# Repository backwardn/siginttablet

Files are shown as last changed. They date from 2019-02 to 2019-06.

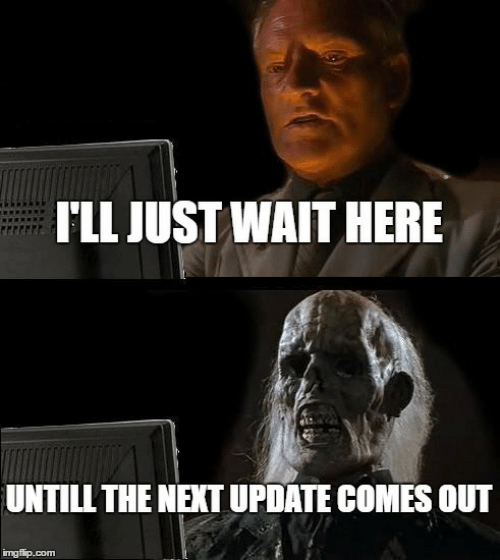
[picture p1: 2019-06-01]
CircleCityCon 2019/assets/ill-just-wait-here-untill-the-next-update-comes-out-26150274.png

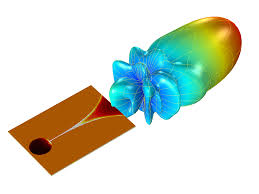
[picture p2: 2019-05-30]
CircleCityCon 2019/assets/vivaldi smith.jpeg

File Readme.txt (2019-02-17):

This is the repository for a Signals Intelligence Tablet, as I will be discussing at the 2019 CircleCityCon

--------------------------------------------
“Who said something? What did they say? Where did they say it? What can I do with it?” These are the questions people have when working with unknown radio systems. This is the art and science of Signals Intelligence (SigInt).

We discuss the basic requirements for working with SigInt, along with a sample platform using a Raspberry Pi and a RTLSDR radio receiver. The discussion will then briefly touch on other hardware that can enable SigInt work, that are not incorporated in the demo platform. We then dive into the software stack that makes SigInt work.

The following software will be used: Linux (Raspbian), RPITX, RTLSDR libraries, GnuRadio (gr-inspector), GQRX, and other accompanying tools. We will use FCC ID’s, manual scanning of spectrum, and gr-inspector to find and target potentially vulnerable frequencies and protocols as well as show how exploits could commence. We will attempt a live demo of such an attack using a system the presenter brings in.
--------------------------------------------

This document will be populated appropriately showing an assembly, recommended 3d printing settings, electrical routing, and configurations for the Raspbian and accompanying software.

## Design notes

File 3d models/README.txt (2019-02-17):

You will need a set of programs to work with these files.

The .fcstd is FreeCAD's data format. This software is Free Software and available for Windows/Mac/Linux. https://www.freecadweb.org/

The .stl's are provided for convenience and are a quick way to print the model. You should never edit STLs. Crappy triangles are crappy. I suggest using MeshLab for visual verification of a model. http://www.meshlab.net/

You will need a slicer to slice the STL to the appropriate gcode for your printer. I will not provide GCode files, since they will *not* work on your printer, unless you built the exact model. 

I would suggest for models 1-4, to print with 100% infill. For #5 (the lid), I have made specific instruction recomenndations for that in the directory.

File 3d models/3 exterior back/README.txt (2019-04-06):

If you have printed the "exterior back.stl" model, and you wish to incorporate a CrazyRadio without another 16h print, do the following:

1. Get a drill with a multitude of bits. 
2. Determine where you want the antenna.
3. Use the smallest bit to start the hole.
4. Work your way up slowly until you get between 6-7mm dia (or whatever that is in imperial)
5. Then work your SMA into the hole, and then tighten the nut. You might have to go back to step 4 if its too small. 
6. Done!

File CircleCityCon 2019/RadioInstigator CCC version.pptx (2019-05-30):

## RadioInstigator

Signals Intelligence Platform

## Who am I?

Josh Conway (CrankyLinuxUser)
FCC Amateur radio: KC9JEF

Facial Recog for your ‘Con (CPU bound, no gpu, no internet)
https://hackaday.com/2015/03/04/face-recognition-for-your-next-con/

Multisite Home/Office/Hackerspace Automation
https://hackaday.io/project/12985-multisite-homeofficehackerspace-automation
Thalmic Labs(North) Shuts Down Free Developer Access Update: It’s Back Again
https://hackaday.com/2014/11/18/thalmic-labs-shuts-down-free-developer-access/

## What is this “Radio” thing, anyways?

## Is this a radio? Is that a radio???

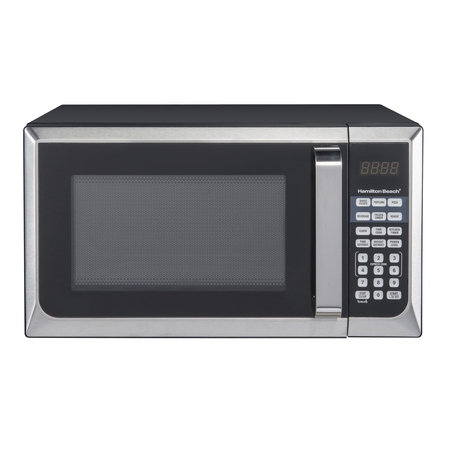
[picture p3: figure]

## They all are!

Definition (noun): The transmission and reception of electromagnetic waves of radio frequency, especially those carrying sound messages.
Definition (verb): communicate or send a message by radio.

## Signals Intelligence

Signals intelligence (SIGINT) is intelligence-gathering by interception of signals, whether communications between people (communications intelligence—abbreviated to COMINT) or from electronic signals not directly used in communication (electronic intelligence—abbreviated to ELINT).
-- Wikipedia

BUT WHY DO WE CARE???

## Common household things… Right?

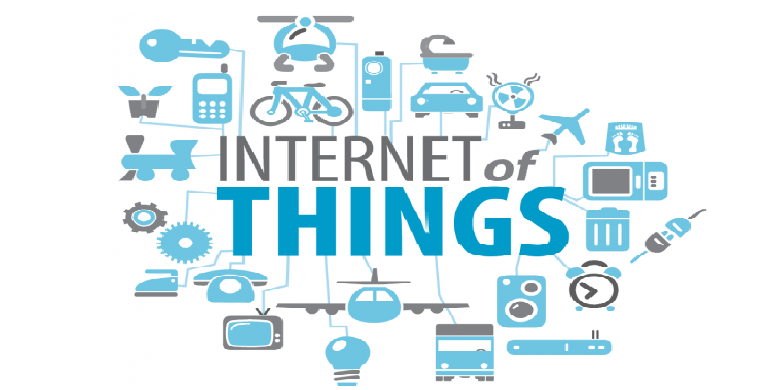
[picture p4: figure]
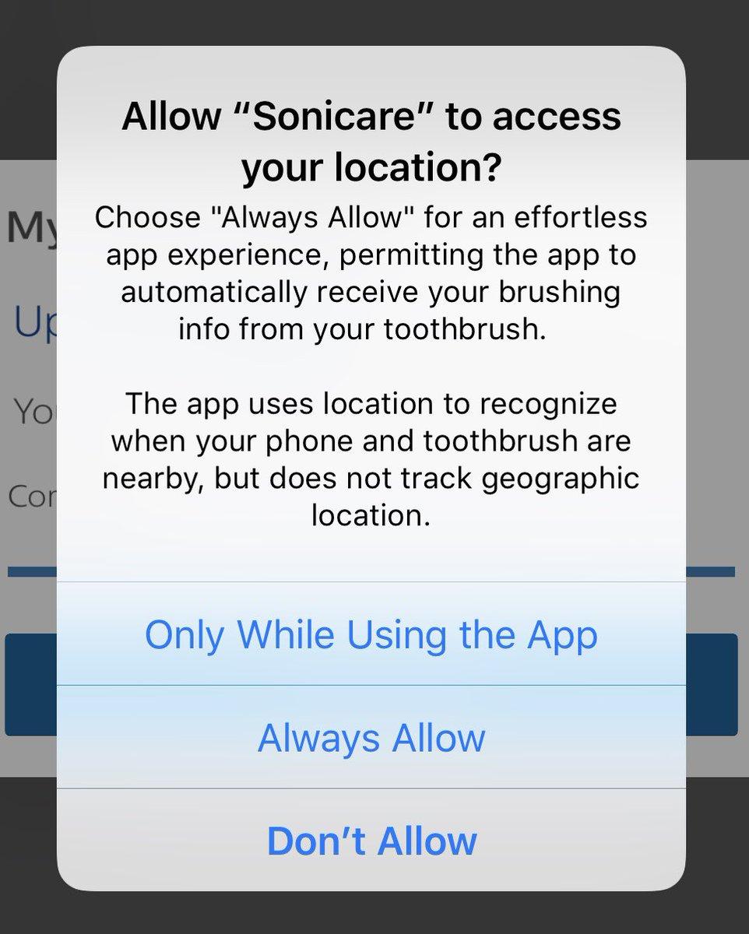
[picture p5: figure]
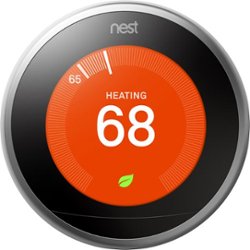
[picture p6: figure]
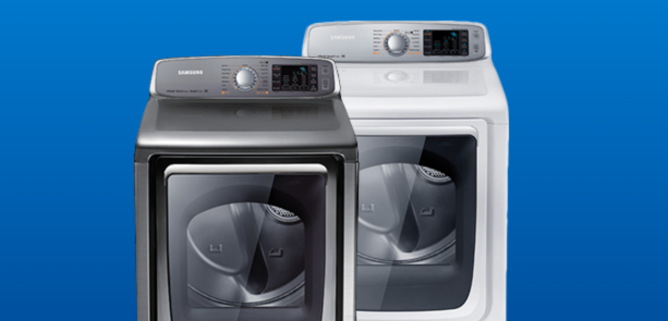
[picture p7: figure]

## Security? Not if we can get away without it!

How many of these are implemented on radios you own?
Are they secure?
Are you sure???

## …. Don’t mind if I do!

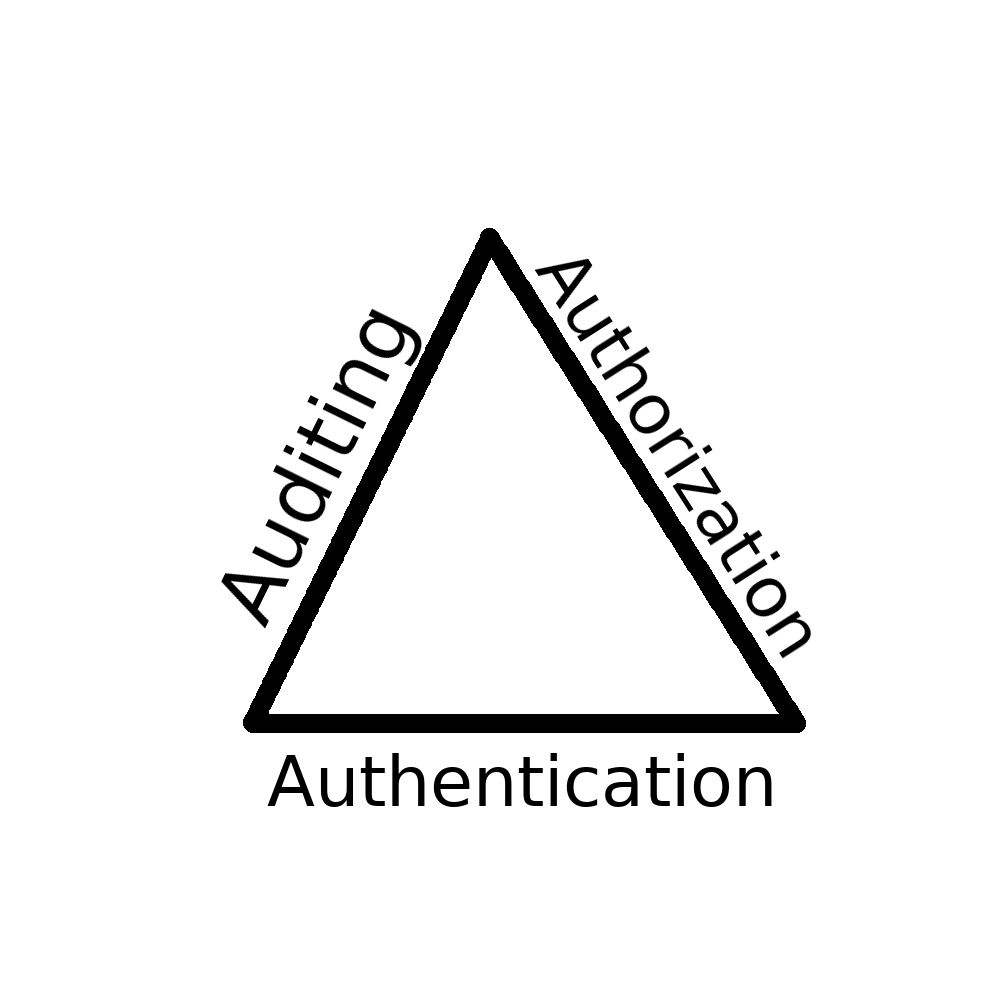
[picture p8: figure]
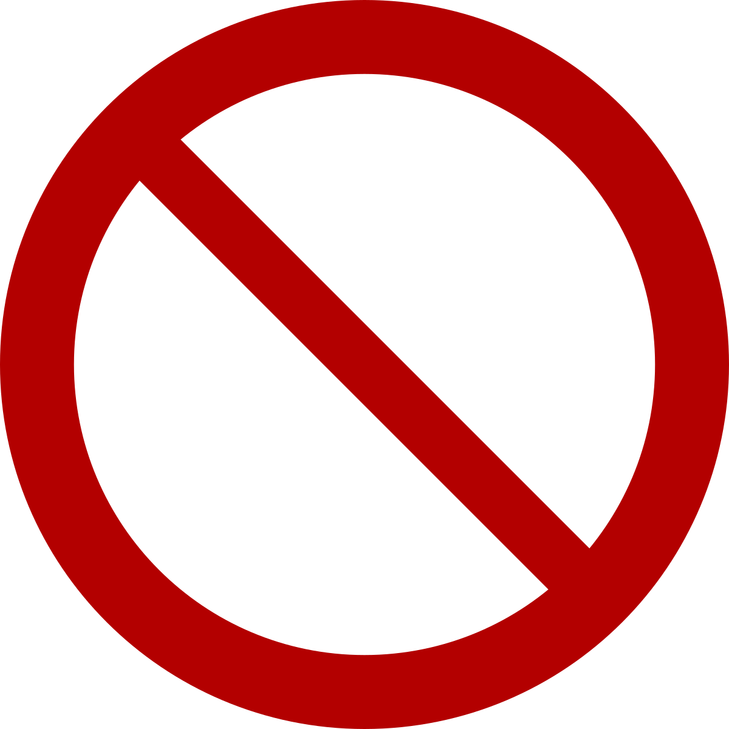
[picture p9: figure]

Unknown
hardware

Unencrypted

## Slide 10

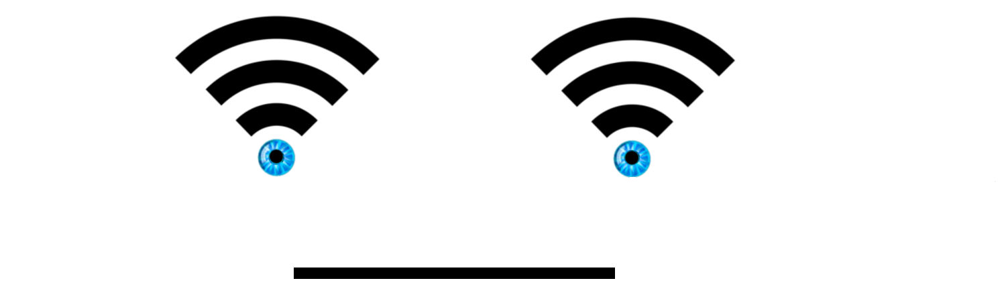
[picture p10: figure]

We are watching you

## My Platform - A $150 Signals Intelligence Tablet

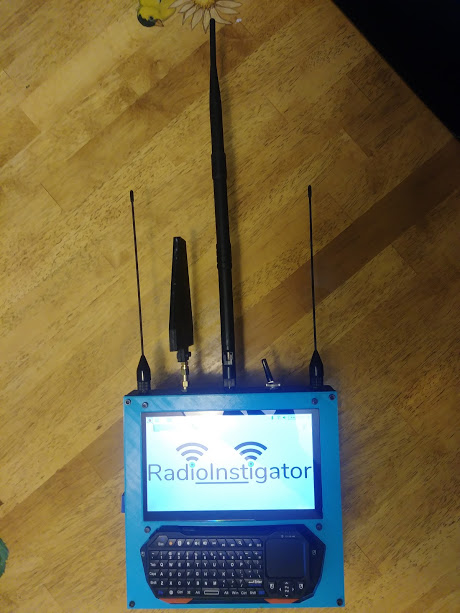
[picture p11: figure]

Raspberry Pi 3 B+
HDMI Touchscreen
RTL-SDR
Keyboard
Cool prints!

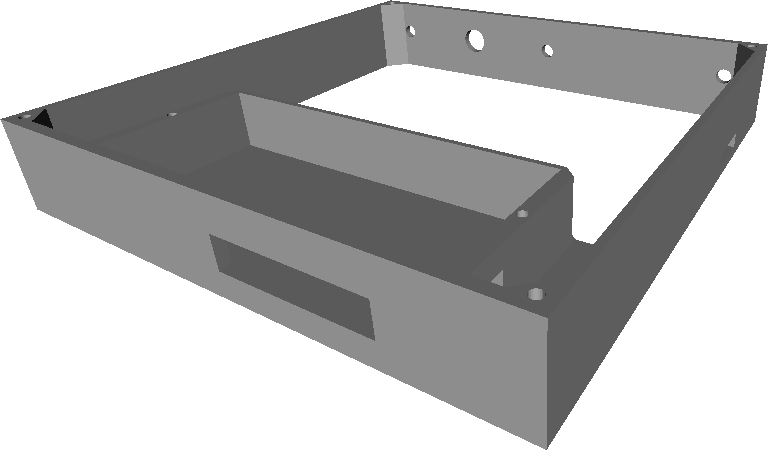
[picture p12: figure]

## You want to build one?

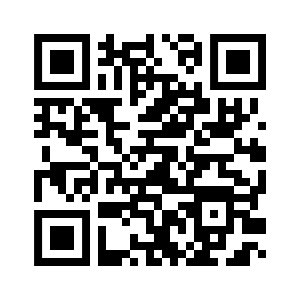
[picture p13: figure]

## SigInt on a shoestring or Dirty SigInt Deeds Done Dirt Cheap

## The Notorious RTL-SDR

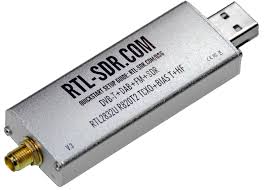
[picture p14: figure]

GOOD | BAD
Cheap Easy to obtain 24MHz-1766MHz 2.4MHz Bandwidth (window) | Cheap Sometimes dubious build quality Janky included antennas

## ADALM-PLUTO

GOOD | BAD
$100-$150 Uber-hackable (dual core Arm with Linux) 70MHz-6GHz (?!) 20MHz Bandwidth (window) Can run programs on device! | Can be hard to obtain 5mW Tx Janky included antennas USB2 limits overall bandwidth

## HackRF

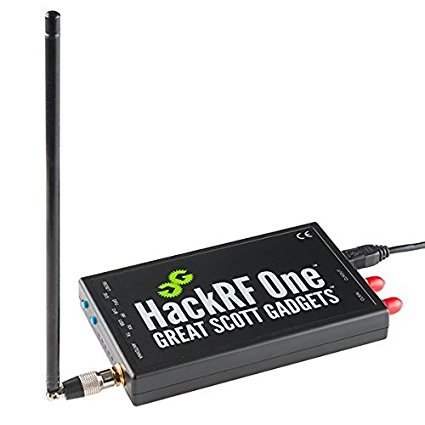
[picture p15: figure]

GOOD | BAD
~$300 Very well supported 1MHz-6GHz (?!?!) Sweep Mode – 8GHz/second | Simplex (Can Tx or Rx, not at the same time) 8 bit IQ

## KerberosSDR

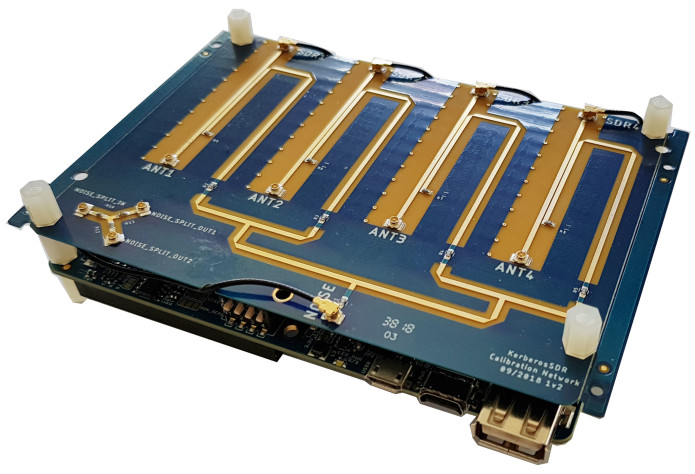
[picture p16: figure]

GOOD | BAD
~$125 Coherent Quad RTL-SDR 24MHz-1.7GHz | Toolchain very ‘raw’ because new 8 bit IQ

## Antennas … Because the ones with the SDR suck

## Omnidirectional Antennas

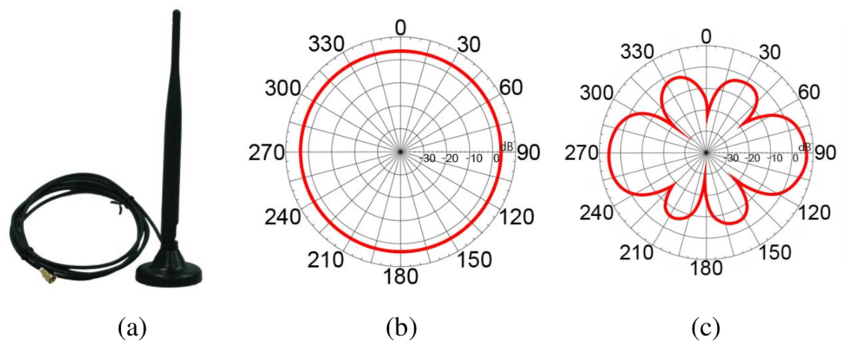
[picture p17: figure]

Horizontal
Polarization

Vertical
Polarization

## Yagi Antennas

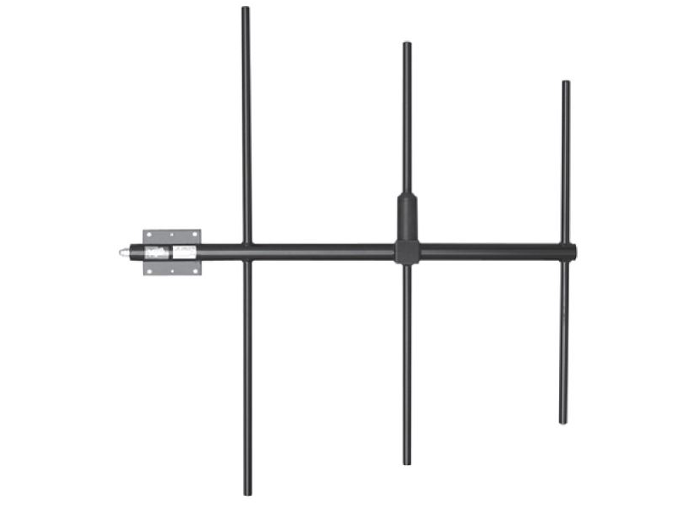
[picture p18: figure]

## Yagi Antennas cont’d

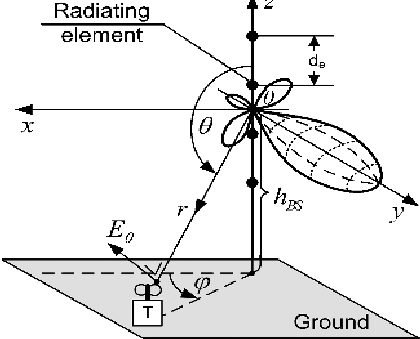
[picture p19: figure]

## Log Parabolic Antennas

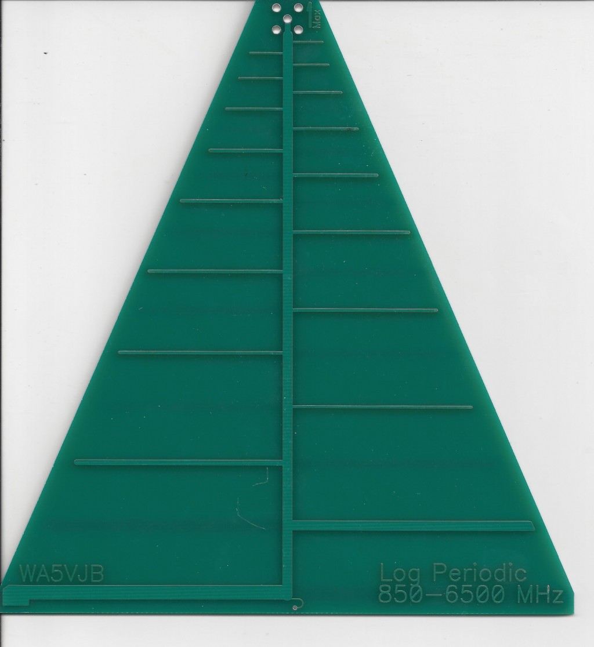
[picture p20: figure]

## Log Parabolic Antennas

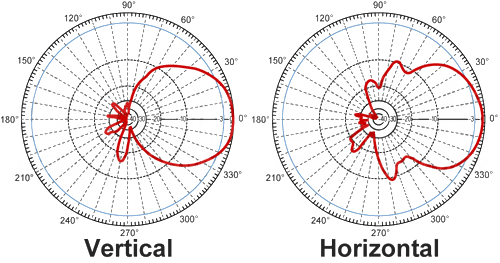
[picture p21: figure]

## Vivaldi Antennas

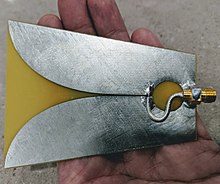
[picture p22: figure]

## Software Whisperer (OS, Libraries)

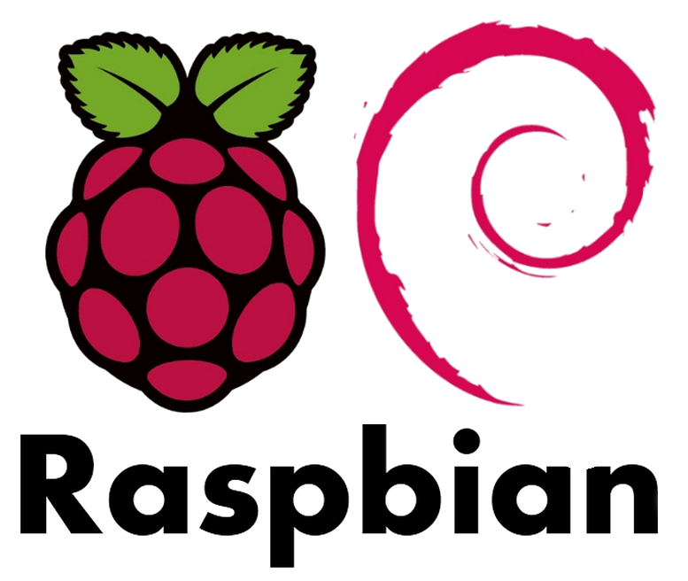
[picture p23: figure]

RPITX Library RTL_SDR Libraries

## Software / GQRX

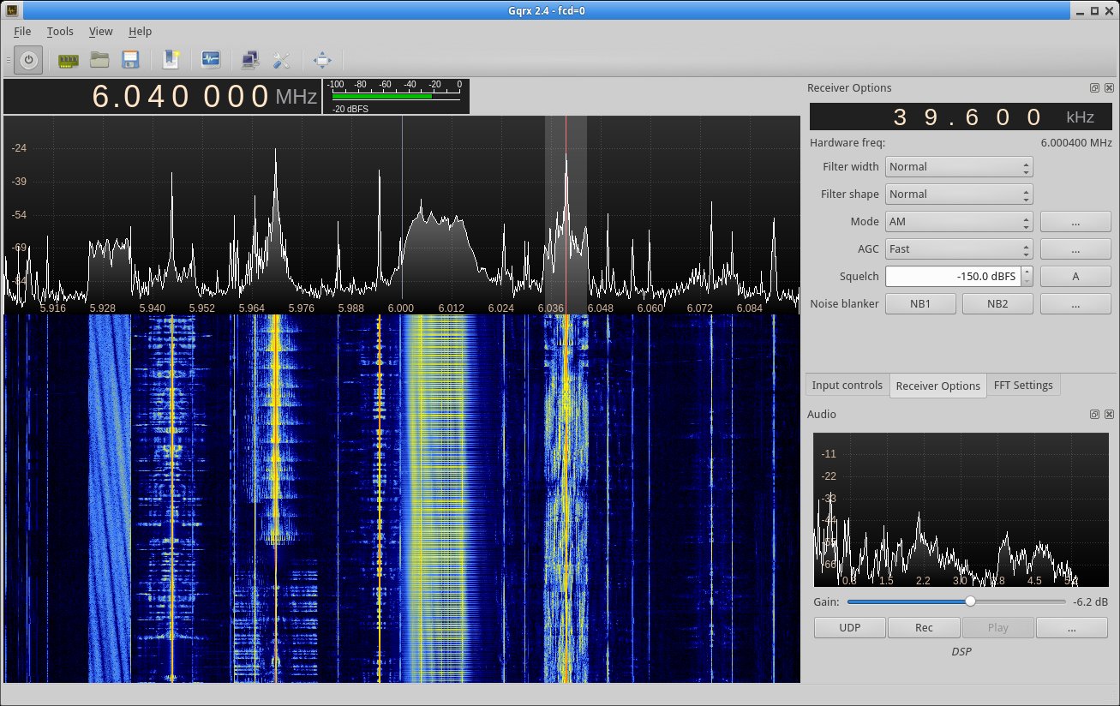
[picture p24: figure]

## Salamandra - Spy Microphone Detector

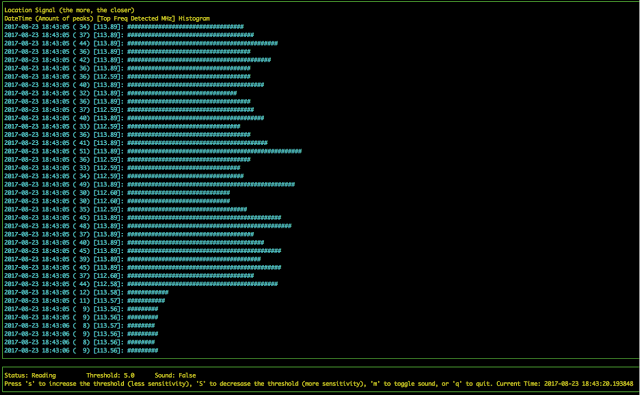
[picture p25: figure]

## TempestSDR - Every Monitor is Wireless

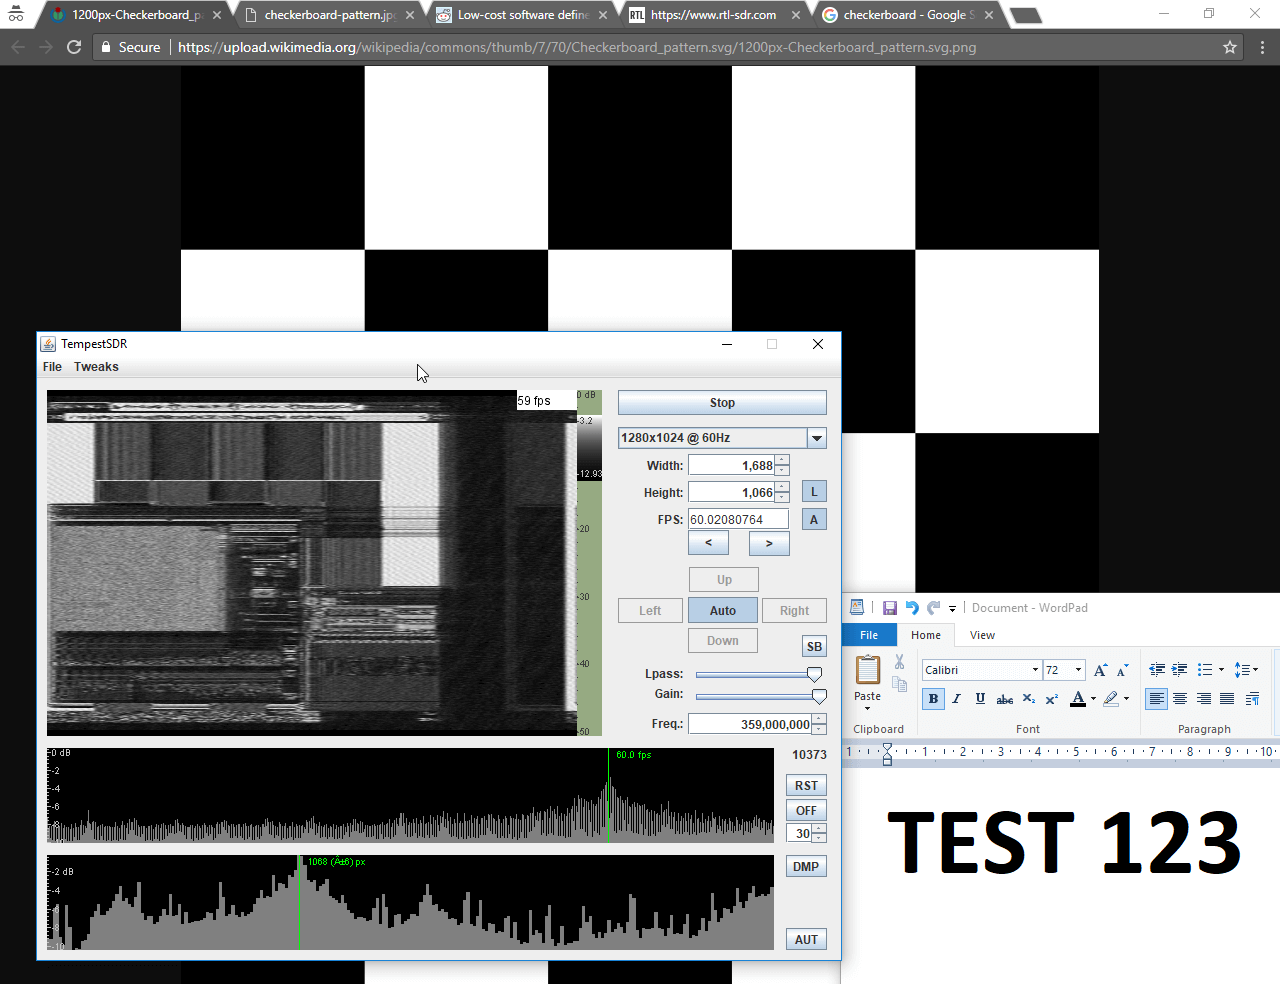
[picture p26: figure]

## Demotime….

## You want to build one?

## RadioInstigator

Signals Intelligence Platform

Josh Conway

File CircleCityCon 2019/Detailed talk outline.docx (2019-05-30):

Introduction (Section:2m, Total:2m)

A. (Myself, nickname, call sign)

B. (Anecdote how presenter forcefully open sourced closed hardware)

C. (Some renowned software presenter made for conventions)

D. Amateur radio operator and 'stuff hacker'

Basics of SigInt (Section:8m, Total:10m)

A. What is it?

1. Signals intelligence (SIGINT) is intelligence-gathering by interception of signals, whether communications between people (communications intelligence—abbreviated to COMINT) or from electronic signals not directly used in communication (electronic intelligence—abbreviated to ELINT). -- Wikipedia

B. Why do we care?

1. Unknown - Lots of things use radio. Equipment to read used to be $$$$ and relied on obscurity. Not now.

2. Unencrypted - Just like IoT, the E stands for Encryption. Most encryption is "we use diff. frequencies"

3. Unauthenticated \

4. Unauthorized |-- AAA Stack. Authentication, Authorization, Auditing. We'll have none of that.

5. Unauditable /

6. HACKED - Various holes enable taking control of endpoints, or listening in on sensitive data

SigInt Platforms (Section:16m , Total:26m)

A. Demo Platform

1. Raspberry Pi 3(All but PiB works)

a. I used RasPi 3 B+

2. Touchscreen that uses DSI or HDMI. Absolutely cannot use GPIO4

a. I used 7 in HDMI with usb power/touchscreen interface

3. RTLSDR dongle

a. I bought the el cheapo $8 Ali express special. Many will work. Make sure to get a TXCO (temp controlled oscillator) enabled

4. Good battery that outputs 2.5A or better USB

5. Antennas

a. omni

b. yagi

c. "weird" antennas

d. freq restrictions of hardware

i. RPi is 10KHz-1.5GHz TX

ii. RTLSDR is 24MHz-1.7GHz RX

iii. Ideal to find 2 antennas good from 24MHz-1.5GHz for symmetric bidirectional comms

6. Odds and ends

a. SMA and RP SMA connectors

b. Kapton tape for insulation

c. Lots and lots of time!

B. Other hardware you can use

1. Transmit & Receive

a. ADALM-PLUTO - 70MHz-6GHz full duplex. 5mw (DINKY) but is only $100 !

b. HackRF One - 1 MHz to 6 GHz single duplex. Tx OR Rx at any given time. ~$300

c. USRP SDRs - set top boxes, USB3 and/or ethernet. $$$$$$$$$

2. Receive only

a. Lots of RTLSDR usb devices. Prices range from $6 to $50. Many form factors. All use the Realtek R820T2 chip

a. KerberosSDR - Coherent "Quad Damage RTLSDR". Shipping Mid-late Jan 2019. Can do triangulation and signal tracking realtime.

b. NooElec NESDR SMArTee XTR - $40 for 65MHz-2300MHz

Software Stacks and Tools (Section:20m, Total:46m)

A. Review of the Fun Tools

1. Linux (Raspbian)

2. RPITX - Library that turns a dumb RPi into a full transmitter from 10KHz-1.5GHz . Also allows TX using raw IQ!

3. rtl_* commands - RTLSDR libraries and commands to natively interact with the RTLSDR. Other programs also rely on them incl RPITX

4. GnuRadio - Best way to build a targeted attack platform for a specific encoding and interaction. Steep curve to learn. Lots of modules.

a. gr-inspector is a ML module to find "Yummies" in signals. Think of this as a radio anomaly detector, so we don't have to look ourselves.

5. GQRX - Really QT frontend for Gnuradio to 'surf the waves' and see what's going on through a swath of spectrum

6. Salamandra - a tool to dynamically find spy microphones. Uses SDR closed loop to catch red handed. Detects AND locates.

7. TempestSDR - SDR tool that receives and decodes RF interference from monitors and shows what they display

(Note to reviewers: SigInt is 'The Next Big Thing', and has a great deal of focus on it right now. This section may expand as new tools are made by myself or the community in the coming months up to the talk. Other sections that will be reduced in time will be 'Other hardware you can use', followed by 'Demo Platform', as the knowledge to DIY it will be more widespread.)

Demonstration (Section:6m, Total:52m)

A. Record/Playback of audio over amateur radio frequency using Demo Platform and Baofeng

B. Replay attack demonstrated of a common 433MHz "arduino" module for IoT setups

Q&A (Section:8m, Total:60m)

Citations (shown on screen, not spoken):

A. RPi

B. RPITX

C. Gnu/Linux

D. Raspbian

E. GnuRadio

F. GQRX

G. Salamandra

H. TempestSDR

Acknowledgements (shown on screen, not spoken):

A. WarCollar industries, for getting me to think in this direction (and awesome story)

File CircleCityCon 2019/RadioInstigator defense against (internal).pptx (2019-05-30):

## RadioInstigator

Signals Intelligence Platform

## What is this “Radio” thing, anyways?


## They all are!

Definition (noun): The transmission and reception of electromagnetic waves of radio frequency, especially those carrying sound messages.
Definition (verb): communicate or send a message by radio.

## Signals Intelligence

Signals intelligence (SIGINT) is intelligence-gathering by interception of signals, whether communications between people (communications intelligence—abbreviated to COMINT) or from electronic signals not directly used in communication (electronic intelligence—abbreviated to ELINT).
-- Wikipedia

BUT WHY DO WE CARE???

## Common household things… Right?


## Security? Not if we can get away without it!


How many of these are implemented on radios you own?
Are they secure?
Are you sure???

## Awareness is Key … At work


## Awareness is Key … At home


## Awareness is Key … On Vacation


Spycam $37 , Amazon


USB cell spy *cable* $12


## Review of Platforms


RTL-SDR - $20 (avg)
Originally a TV tuner card for Asian TV
Can Receive only 20 MHz-1.7GHz

## Review of Platforms

ADALM-PLUTO - $100
Dedicated Transmit/Receive Software Radio
Transmit/Receive 70MHz-6GHz


## My Platform - A $150 Signals Intelligence Tablet


Raspberry Pi 3 B+
HDMI Touchscreen
RTL-SDR
Keyboard
Cool prints!


## Software Whisperer (OS, Libraries)


RPITX Library RTL_SDR Libraries

## Software / GQRX


## Salamandra - Spy Microphone Detector


## TempestSDR - Every Monitor is Wireless


## Demotime….

## You want to build one?


## RadioInstigator

Signals Intelligence Platform

Josh Conway

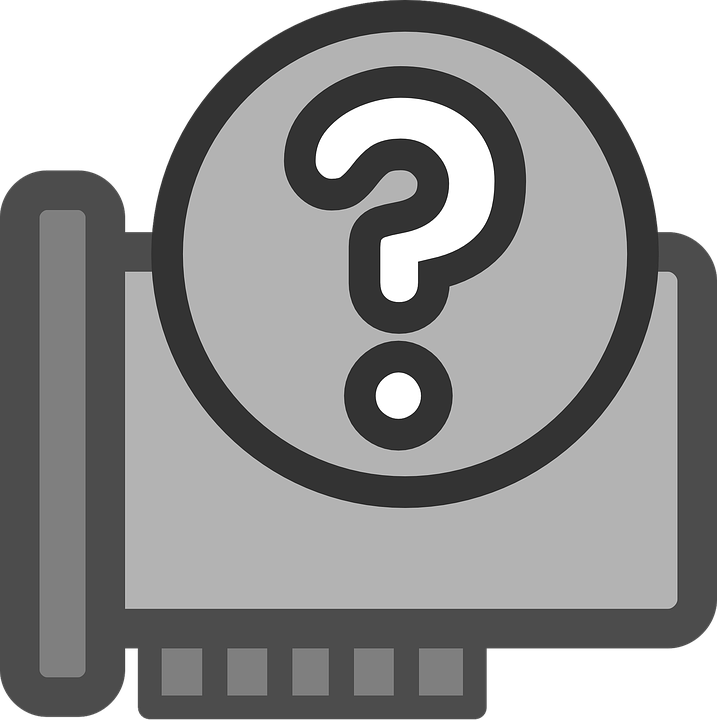
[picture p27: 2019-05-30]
CircleCityCon 2019/assets/unknown hardware.png

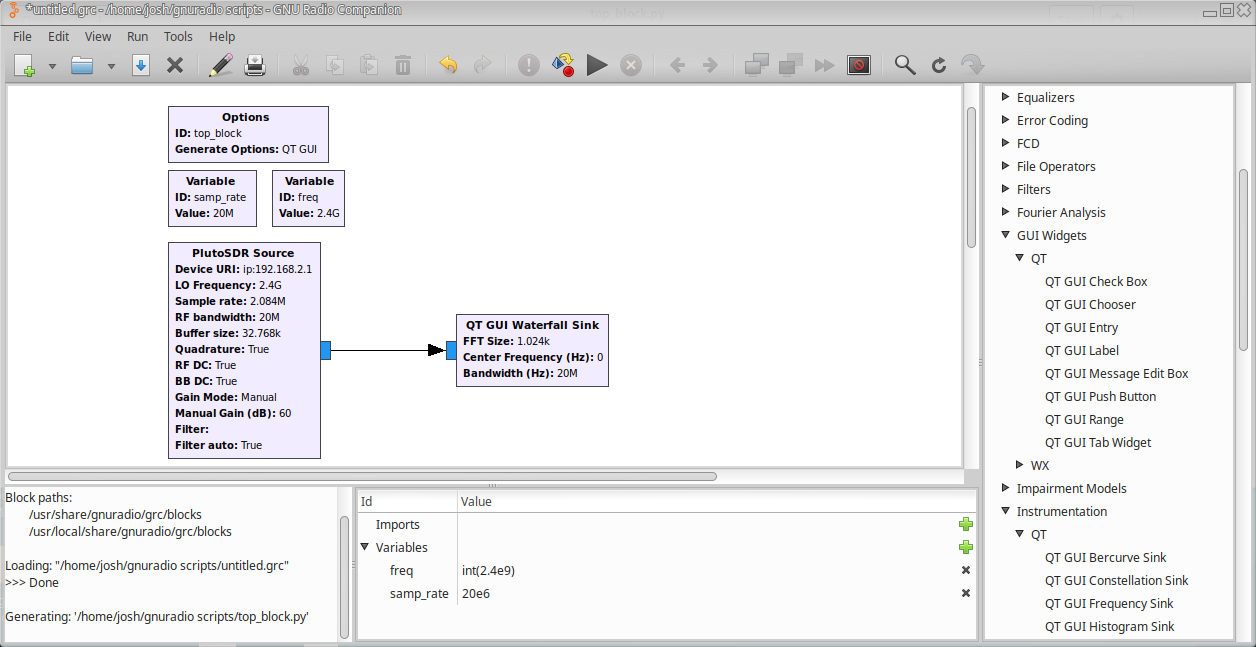
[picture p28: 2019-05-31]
CircleCityCon 2019/assets/gnuradio.png

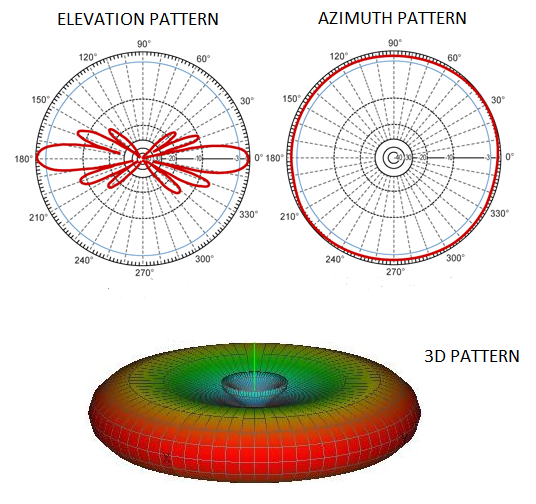
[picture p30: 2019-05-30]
CircleCityCon 2019/assets/smith chart view.png

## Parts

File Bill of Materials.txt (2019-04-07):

This is a list of materials you will need to complete this tablet.

Please be aware, that since the product links are to a variety of auction sites, these prices **WILL** change. I also considered a few things as 0 cost. For example, USB cables are ubiquitious. We cut a few up. 

I also have a large format 3d printer. You probably don't. I didn't include cost for printables, or nuts and bolts. I buy in quantity from Fastenal or McMaster Carr. 

Total cost tally as of 17 Feb 2019: $157.50

	-- 3d Printables --

0. The printables. I have my own printer. You need a full printable size of 200mm x 200mm to print these parts

	-- Electronics --

1. Raspberry Pi 3 B+ $36.00
https://www.ebay.com/itm/Raspberry-PI-3-Model-B-Quad-Core-64-Bit-1GB-WIFI-Motherboard-PC-Computer-NEW/232120229741

2. MicroSD card (salvaged from other projects) $0

3. PWRbar 10AH battery (purchased from Office Depot on sale) $5
https://www.officedepot.com/a/products/757106/PWR-Bar-10000-mAh-Micro-USB/

4. LCD Touchscreen $58.00
https://www.ebay.com/itm/7-Inch-1024-600-Capacitive-Touch-Screen-HDMI-TFT-LCD-Display-for-Raspberry-Pi/263427485642

5. RTL-SDR $9.50
https://www.aliexpress.com/item/Useful-Usb2-0-DAB-FM-DVB-T-RTL-SDR-Dongle-vara-RTL2832-R820T-SDR-Digital-TV/32812258737.html

6. IS11-BT05 Bluetooth keyboard $20

7. Random USB wifi that Kali linux liked, junked find 0$

8. (OPTIONAL) CrazyRadio , allows easy keyboard mouse sniffing/injection for wide variety of hardware $8
https://www.ebay.com/itm/Crazyradio-2-4Ghz-nRF24LU1-USB-radio-dongle-with-antenna-for-Crzayflie-10DOF/231423427319

9. (OPTIONAL) (WARNING) GPS chip , bought on AliExpress for $10 but cannot find anywhere. Dealer no longer is there.

	-- Cables --

10. MCX to SMA adapter $4
https://www.ebay.com/itm/6-SMA-Female-Nut-Bulkhead-to-MCX-Male-Straight-RG316-cable-pigtail-US-Stock/111782431584

11. SMA female to jumper lead $2
https://www.ebay.com/itm/SMA-Female-Jack-W-Nut-Bulkhead-Pigtail-RF-Jumper-Cable-1-13mm-f-PCB-Board-10cm/253447841441

12. 50cm HDMI ribbon $8
https://www.ebay.com/itm/50cm-FPV-Dual-90-Degree-Up-Angled-HDMI-Type-A-Male-to-Male-HDTV-FPC-Flat-Cable/163407521002

13. Pile of "donor" micro USB cables $0

14. SPST Switch. 11mm diameter. Radio Shack deal. $1 

	-- Antennas --

15. Really long wifi antenna found with above usb device 0$

16. 2 Antennas 50MHz-1200MHz $20
Ebay store closed... :/ I need a reliable source. This will likely balloon the budget.

17. (OPTIONAL) Log Peroidic Antenna $9.20
https://www.ebay.com/itm/15W-5-6dB-1-35-9-5GHz-UWB-Ultra-Wideband-Logarithmic-Period-Antenna/292695546650

	-- Screws/Nuts --

18. M3X45 cap screws (X4)

19. M3 nut (x4)

20. M3X16 cap screws (X6)

21. M3 Heat set inserts, 4.3mm tall (X4)
https://www.mcmaster.com/94459A130
NOTE: If you redesign the back cover for M3 nuts, you can use them instead. It won't look as finished, but will certainly work.

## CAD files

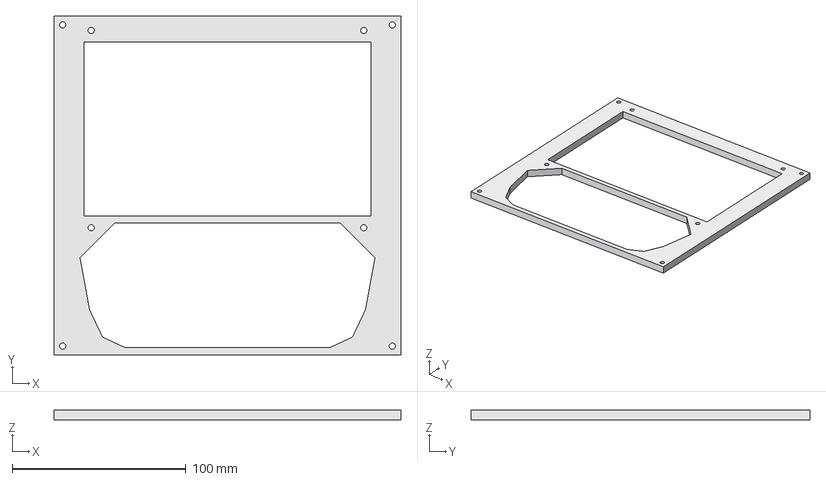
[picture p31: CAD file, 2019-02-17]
3d models/1 top bezel case/top bezel case final.fcstd
200.0 x 195.2 x 6.00 mm

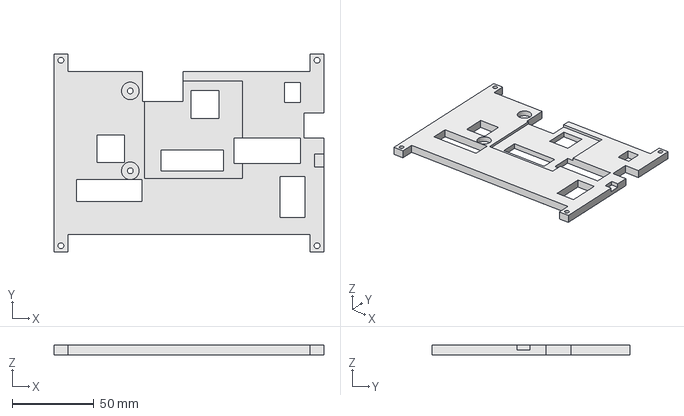
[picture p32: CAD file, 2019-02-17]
3d models/2 lcd backplane/LCD backplate.fcstd
165.6 x 121.2 x 6.05 mm

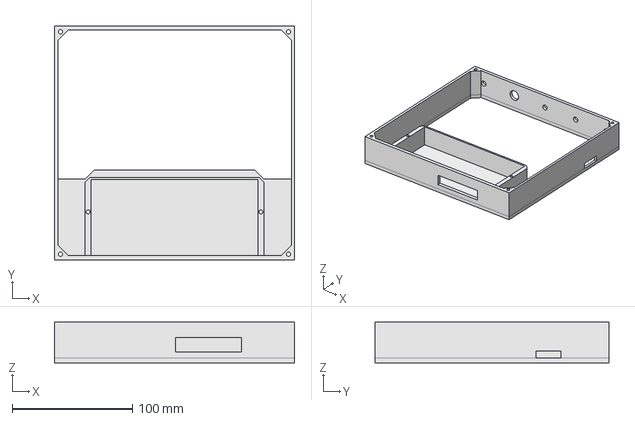
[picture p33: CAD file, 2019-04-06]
3d models/3 exterior back/exterior back with crazyradio.fcstd
200.0 x 195.2 x 34.0 mm

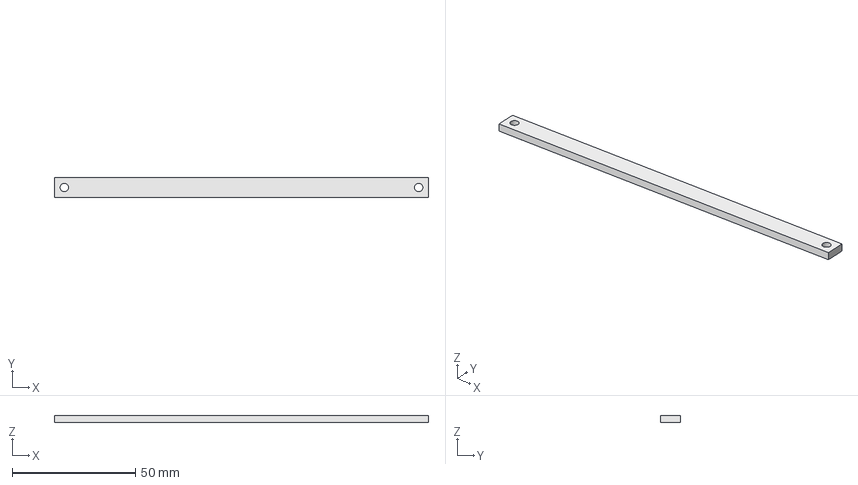
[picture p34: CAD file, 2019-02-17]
3d models/4 battery bar/battery bar.fcstd
152.0 x 8.00 x 3.00 mm

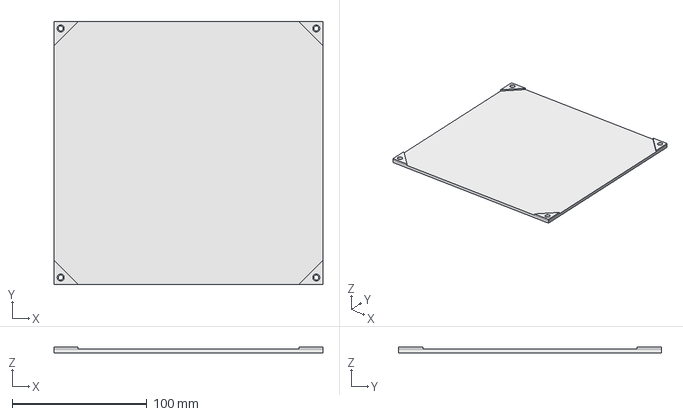
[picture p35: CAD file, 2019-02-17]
3d models/5 back plate/back plate.fcstd
200.0 x 195.2 x 4.50 mm

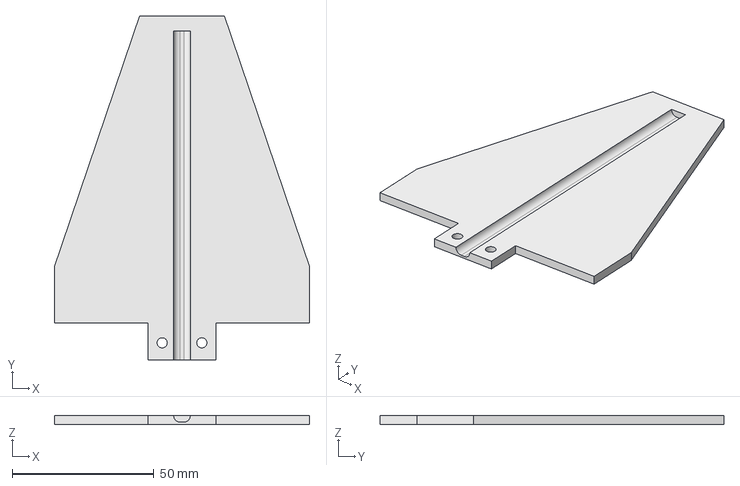
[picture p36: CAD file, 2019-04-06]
3d models/6 antenna case/top antenna.fcstd
90.0 x 121.3 x 3.00 mm

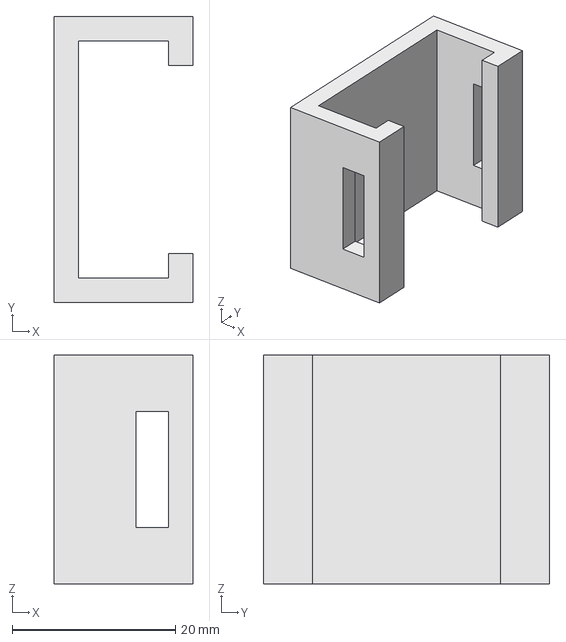
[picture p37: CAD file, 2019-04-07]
3d models/7 gps holder/gps holder.fcstd
17.0 x 35.0 x 28.0 mm

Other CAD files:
3d models/3 exterior back/exterior back.fcstd
3d models/6 antenna case/bottom antenna.fcstd
3d models/1 top bezel case/top bezel case final.stl
3d models/2 lcd backplane/lcd backplate.stl
3d models/3 exterior back/exterior back with crazyradio.stl
3d models/3 exterior back/exterior back.stl
3d models/4 battery bar/battery bar.stl
3d models/5 back plate/back plate.stl
3d models/6 antenna case/bottom antenna.stl
3d models/6 antenna case/top antenna.stl
3d models/7 gps holder/gps holder.stl

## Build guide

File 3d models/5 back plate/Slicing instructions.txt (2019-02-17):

To slice, I used Slic3r.

I'm using a .4mm nozzle, with .2mm layer height for all layers
I set infill to 40%, honeycomb.
I set Horizontal shells (bottom AND top) to 0. This expresses the infill to the seethrough effect I have

Once you regenerate the slice, view the layers tab on the bottom of the 3d interface. 
You want to check and verify the layers are doing what you want. 

Once you're happy with how the lid effect is expressed, generate the GCode and send to printer

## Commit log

2019-02-17 Adding 3d printing readme
2019-04-06 added crazyradio model
    [exterior back with crazyradio.fcstd, exterior back with crazyradio.stl]
2019-04-06 log period model, updated BoM, made notes for updated model
    [bottom antenna.fcstd, bottom antenna.stl, top antenna.fcstd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]
2019-04-07 added GPS holder
    [gps holder.fcstd, gps holder.stl]
